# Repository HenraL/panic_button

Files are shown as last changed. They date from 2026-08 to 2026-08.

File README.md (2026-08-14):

<!-- 
-- +==== BEGIN AsperHeader =================+
-- LOGO:
--               @@@@@@@@@
--            @@@@       @@@@
--           @@  @@@@@@@@@  @@
--             @@@  @@@  @@@
--               @@@@@@@@@
--               @@ @@@ @@
--                 @@@@@
--                   @
--                  @@@
--                 @- #@
--                 @: @@
--                  @ @
--                  @ @
--                  @ @
--                 -@ @:
--                 =@ @*
--                 ## -#
--               %@@@@%@@@
--               @       @@
--            -@%@@@@#%@@@@@+
--         @@%+             =%@%#
--      =@@.                    @@#
--     %@:                       *@@-
--   *@*                           *%%
--  #@=         .   +*=             +@%
--  @*         :@@@@+-+@@@=          *@
-- %@          @@-        @@%         @@
-- %@         @%  %@@-@@@  #@         @@
-- @+        %@= @@     @@  @@        +@
-- @+        *@- @@     @@ -@%        +@
-- %@         @%  =@@@@@#  #@         @@
-- *@:         @@%       *@@+        :@%
--  @#           @%@*+@@%@#          #@
--  #@%                           . #@*
--    @%                           %@
--     @%@                       @@%
--      -@@%                   #@@=
--         *@@@             @@@#
--             @%@@@@@@@@@@@+
-- /STOP
-- PROJECT: AsperHeader
-- FILE: README.md
-- CREATION DATE: 14-08-2026
-- LAST Modified: 2:57:22 14-08-2026
-- DESCRIPTION:
-- A small panic beacon: reports its position to a server, falls back to SMS when unreachable, and advertises BLE (Find My-style) so phones can interact with it without an app.
-- /STOP
-- COPYRIGHT: (c) Asperguide
-- PURPOSE: This is the file in charge of introducing the repository.
-- // AR
-- +==== END AsperHeader =================+
-->
# Panic Button

A small **panic beacon** (target: no bigger than a finger; a palm if that size can't be
reached) that:

1. Updates its position towards a server.
2. If that is not available, sends an SMS (or similar).
3. Regardless of the above, advertises a BLE beacon (Apple Find My-style, Android hub,
   Samsung if they stray) so nearby phones can interact with it without any app.

Apple UWB is out of reach (proprietary Apple U1/U2 chip + MFi program) — phone interaction is
BLE only. Cost target: **< $50 / unit** (excluding the IoT/SIM plan).

## Repository layout

- `AGENTS.md` — rules and conventions for AI agents and contributors; read it first.
- `KiCad/v1/panic_button` — first board attempt (archive).
- `KiCad/v2/dev/panic_button_dev` — dev variant of the v2 circuit.
- `KiCad/v2/tiny/panic_button_tiny` — **active design** (KiCad 10): the tiny variant,
  as small as possible.
- `KiCad/v2/tiny/bom.md` — live bill of materials (strictly the BOM).
- `KiCad/v2/tiny/design.md` — design decisions, notes and open questions.
- `platformio/` — firmware (PlatformIO + Arduino on ESP32-C3). Comes **after** the circuit
  planning, not in parallel.
- `bonus/` — tools / environments / scratch (`bonus/tmp/`).

## Hardware status

- **Tiny** (active): ESP32-C3 (BLE) + SIM7670G LTE Cat1 (GNSS, SMS, HTTP/MQTT), Li-ion +
  USB-C charging, wake-on-motion accelerometer. Schematic in progress in KiCad 10.
- **Dev** = the tiny circuit + test infrastructure (test points, button array, richer LEDs,
  AirM2M Core ESP32-C3 module as the easier-to-mount MCU), functionally identical.

See `bom.md` for parts and prices, `design.md` for decisions.

## License

MIT — see `LICENSE`.

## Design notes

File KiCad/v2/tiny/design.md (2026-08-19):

<!-- 
-- +==== BEGIN AsperHeader =================+
-- LOGO:
--               @@@@@@@@@
--            @@@@       @@@@
--           @@  @@@@@@@@@  @@
--             @@@  @@@  @@@
--               @@@@@@@@@
--               @@ @@@ @@
--                 @@@@@
--                   @
--                  @@@
--                 @- #@
--                 @: @@
--                  @ @
--                  @ @
--                  @ @
--                 -@ @:
--                 =@ @*
--                 ## -#
--               %@@@@%@@@
--               @       @@
--            -@%@@@@#%@@@@@+
--         @@%+             =%@%#
--      =@@.                    @@#
--     %@:                       *@@-
--   *@*                           *%%
--  #@=         .   +*=             +@%
--  @*         :@@@@+-+@@@=          *@
-- %@          @@-        @@%         @@
-- %@         @%  %@@-@@@  #@         @@
-- @+        %@= @@     @@  @@        +@
-- @+        *@- @@     @@ -@%        +@
-- %@         @%  =@@@@@#  #@         @@
-- *@:         @@%       *@@+        :@%
--  @#           @%@*+@@%@#          #@
--  #@%                           . #@*
--    @%                           %@
--     @%@                       @@%
--      -@@%                   #@@=
--         *@@@             @@@#
--             @%@@@@@@@@@@@+
-- /STOP
-- PROJECT: AsperHeader
-- FILE: design.md
-- CREATION DATE: 14-08-2026
-- LAST Modified: 14:21:28 14-08-2026
-- DESCRIPTION:
-- A small panic beacon: reports its position to a server, falls back to SMS when unreachable, and advertises BLE (Find My-style) so phones can interact with it without an app.
-- /STOP
-- COPYRIGHT: (c) Asperguide
-- PURPOSE: This is the file containing the intended design of the circuit and why.
-- // AR
-- +==== END AsperHeader =================+
-->
# Design notes — panic_button_tiny (KiCad v2, "tiny" variant)

Working document for ideas, decisions, and open questions around the circuit. This is the
"sorting bin" — the strict bill of materials lives in `bom.md`.

## Goal

A **panic beacon** — small device (target: no bigger than a finger; a palm if that size can't
be reached). General-purpose; the current `tiny` variant happens to target a cat collar
(user's use case), but the design is not tied to that form factor.

Same family as the earlier v1/v2 dev designs, shrunk as far as practical.

## Tiny vs dev

- **Tiny** = the smallest possible circuit, as arranged in `panic_button_tiny/`.
- **Dev** = the tiny circuit + test infrastructure: test points, a testing array of buttons,
  richer debug status LEDs, and an **AirM2M Core ESP32-C3 module** as the easier-to-mount C3
  (same ESP32-C3FH4 die as the tiny's bare QFN, castellated module, onboard USB-C/buttons/RGB
  LED — Arduino framework supported). Functionally identical, same
  BOM family — any part dropped in tiny for footprint reasons is dropped in dev too. Dev
  extras only make the circuit easier to probe/debug; they never change what the circuit does.

## Hard functional spec (both variants)

1. Update the beacon's position towards a server.
2. If that is not available, send an SMS (or similar).
3. Regardless of the above, advertise BLE so phones can interact without an app
   (Apple Find My-style, Android hub, Samsung if they deviate).

Concretely the modem must provide: **a GNSS position fix, SMS, and HTTP/HTTPS + MQTT
(or similar) over LTE, all via AT commands**. Any modem substitution must keep all three.

## Decisions made

- **No UWB.** Apple UWB requires Apple's proprietary U1/U2 chip + MFi program — not reachable
  from an ESP32. Phone interaction relies on **BLE beacons only**:
  - Apple: Find My network accessory profile (BLE, keys-based, app-less).
  - Android: Find My Device hub (BLE).
  - Samsung: SmartThings Find (BLE, if they deviate from Android's hub).
- **Modem: SIM7670G** (24×24 mm) — the realistic floor for "Cat1 + GNSS + SMS + HTTP/MQTT in
  one part". Smaller Cat1 modules (EC200U, L610) are the same size class without GNSS; going
  smaller means LTE-M (loses SMS guarantees + needs a separate GNSS chip). Unless the
  footprint ceiling demands it, SIM7670G stays.
- **Position** comes from the SIM7670G's built-in GNSS (the `G` variant), with LTE cell
  triangulation as a fallback → POST to the server via HTTP(S) over LTE.
- **"If movement"** requires a MEMS accelerometer with a wake-on-motion interrupt to wake the
  MCU from deep sleep — neither the ESP32-C3 nor the modem can sense motion.
- **BMS is a DW01A-enable toggle (reworked 19-08-2026).** U6 (DW01A) + U7 (8205A) are
  **always populated**; the 8205A FETs are the only cell − → GND path. The toggle is a
  2-pad testpoint switch in the DW01A's GND pin (µA — nothing heats, no power-path switch):
  - Jumper **open** (default — cell with internal protection PCB, typical 603050 pouch):
    DW01A dead (no return path), OD/OC held high by **R12/R13 (470 kΩ) pull-ups to +BATT**
    → both gates on → the FETs conduct like a wire; the battery's own BMS owns the cell.
  - Jumper **bridged** (bare cell, no BMS): DW01A powered (VCC → BT1 (+) pre-switch, so
    protection stays armed while charging with the device off) → overcharge /
    overdischarge / overcurrent protection through the 8205A gates.
  - Silkscreen: "link only if the battery does not have a BMS; otherwise leave open".
- **Reverse-polarity protection: one high-side P-FET (Q1 = Si2305CDS, SOT-23).** The
  DW01A/8205A combo protects the cell, not a reversed plug — a reversed battery forward
  biases every body diode and kills the charger. Q1 (source = SW4 output, drain = +BATT,
  gate = GND) blocks that with zero drop. **Q2 (Si2301CDS) has no role — drop it.**
- **Reverse-powering protection (19-08-2026) — what protects what, and the rule:**
  - **Never series-diode the main rails** (+BATT, 3.3 V) — the 0.3–0.5 V Schottky drop is
    unacceptable in a battery device; that's exactly why Q1 is a FET (zero-drop ideal diode).
  - **Cell:** Q1 covers reversed cell insertion; DW01A/8205A block reverse cell current.
  - **5 V/VBUS (J2):** a series Schottky (SS14/SS24) blocks a reversed or mis-wired USB /
    bench supply — the TP4056 has no internal reverse-VBUS protection. [ADD, optional but
    cheap]. The optional USBLC6-2SC6 ESD sits on VBUS/CC for surges.
  - **J3 programming header:** the R10/R11 series resistors on U0TXD/U0RXD already block
    backfeed / reversed-plug damage to the C3 pins. Leave the J3 3V3 pin **unwired** (board
    is self-powered while flashing) or run it through a Schottky — never a straight
    connection to a live rail.
  - **Bench-lab safety net:** a TVS (e.g. 5 V on VBUS, 3.3 V on the 3V3 rail) clamps
    over/under-voltages; a reversed voltage forward-biases it → shorts → a series PPTC fuse
    opens. Only worth it if the device will be probed by hand a lot.
- **Battery-status LEDs on the charger** (LED1 red = charging, LED2 green = charged, off the
  TP4056 CHRG/STDBY open-drain outputs via R6/R7 1 kΩ) — wired, zero GPIOs, and the
  "charge status on the LED" spec is satisfied without touching the ESP. A GPIO-driven
  variant (drop Y2 → GPIO0/1) was considered and shelved as redundant.

## Firmware (PlatformIO)

- **One shared codebase** in `platformio/` — the same firmware for whatever PCB it ends up on.
- The `board = ...` declaration in `platformio.ini` acts mainly as a **RAM/flash + build-flag
  reference** (e.g. an ESP32-C3 board def) — it is not tied to our physical boards or their
  components.
- Less desirable alternative, still available: define **our own board entry** in the PIO
  config (custom memory/flags) instead of borrowing a stock one.

## Power / sleep notes

- SIM7670G supply range 3.4–4.3 V (typ. 4.0 V). A bare Li-ion (3.2–4.2 V) can sag under TX
  bursts — plan a steady 4 V rail (boost) or a fat bulk capacitor, plus a load switch so the
  modem draws nothing in deep sleep.
- Deep-sleep modem-off budget should let the beacon sit for weeks; wake only on motion
  interrupt, panic button, or periodic heart-beat timer.
- Each position report is a ~2 A burst for a few seconds — bulk caps on the modem rail matter
  as much as the cell.

## Component review (14-08-2026)

BOM checked against the target (< $50 excl. IoT plan) — still feasible at ~$20–46. Picks and
why:

- **Antenna for the C3**: the bare chip has no antenna in/on it (dev boards like the AirM2M
  Core / SuperMini carry their own PCB antenna). The tiny needs a **2.4 GHz SMD ceramic chip
  antenna (2450AT43A100-class) + LC matching network**, kept close to the RF pad / feed.
- **Modem stays SIM7670G**: cheaper Cat1 parts (e.g. A7670E / SIM7600-family variants) drop
  GNSS, which fails the hard spec (GNSS + SMS + HTTP/MQTT in one part).
- **Charger: TP4054** (SOT-23-5) instead of TP4056/IP5306 — smallest footprint, right current
  class; TP4056 only if we want the CHRG/STDBY LED pins; IP5306 rejected (5 V boost PMIC,
  wrong tool, bigger).
- **Accelerometer: LIS2DW12** (2×2 mm, ~7 µA). BMA400 as an alternative only if autonomous
  activity detection ever matters (10 µA, slightly pricier).
- **Modem rail**: low-quiescent boost in the ~1 A class (TPS61099-like) plus bulk caps covers
  the 2 A TX bursts; a higher-current part (TPS61023-like) is the headroom option. Both to be
  confirmed against the SIM7670G's burst profile + load switch for sleep.
- **USB-C charge-only**: 4/6-pin receptacle + 5.1 kΩ CC pull-downs; no D+/D- (tiny flashes
  via UART0 pads).

## Open questions

- Footprint ceiling for the cat: is a flat ~30×24 mm collar puck acceptable, or must the
  design fight for something smaller (which re-opens the modem question)?
- Report cadence when moving (sets cell size + charging expectations).
- One LED or none on the tiny version?
- Boot/reset as test pads instead of buttons on the tiny version (no switches on the cat)?
- Waterproofing strategy (sealed USB-C, charging contacts, enclosure) — shapes the final
  form factor.

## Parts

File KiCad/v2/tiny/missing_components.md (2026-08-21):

<!-- 
-- +==== BEGIN AsperHeader =================+
-- LOGO:
--               @@@@@@@@@
--            @@@@       @@@@
--           @@  @@@@@@@@@  @@
--             @@@  @@@  @@@
--               @@@@@@@@@
--               @@ @@@ @@
--                 @@@@@
--                   @
--                  @@@
--                 @- #@
--                 @: @@
--                  @ @
--                  @ @
--                  @ @
--                 -@ @:
--                 =@ @*
--                 ## -#
--               %@@@@%@@@
--               @       @@
--            -@%@@@@#%@@@@@+
--         @@%+             =%@%#
--      =@@.                    @@#
--     %@:                       *@@-
--   *@*                           *%%
--  #@=         .   +*=             +@%
--  @*         :@@@@+-+@@@=          *@
-- %@          @@-        @@%         @@
-- %@         @%  %@@-@@@  #@         @@
-- @+        %@= @@     @@  @@        +@
-- @+        *@- @@     @@ -@%        +@
-- %@         @%  =@@@@@#  #@         @@
-- *@:         @@%       *@@+        :@*
--  @#           @%@*+@@%@#          #@
--  #@%                           . #@*
--    @%                           %@
--     @%@                       @@%
--      -@@%                   #@@=
--         *@@@             @@@#
--             @%@@@@@@@@@@@+
-- /STOP
-- PROJECT: AsperHeader
-- FILE: missing_components.md
-- CREATION DATE: 16-08-2026
-- LAST Modified: 19:20:52 20-08-2026
-- DESCRIPTION:
-- A small panic beacon: reports its position to a server, falls back to SMS when unreachable, and advertises BLE (Find My-style) so phones can interact with it without an app.
-- /STOP
-- COPYRIGHT: (c) Asperguide
-- PURPOSE: This file lists every component the schematic still lacks, the symbol/footprint to use, and where each one links (pin numbers / nets).
-- // AR
-- +==== END AsperHeader =================+
-->
# Missing & present components — panic_button_tiny (as of 20-08-2026)

Complete wiring ledger, pin by pin. Verified against the saved schematic files
(embedded symbols, Y-flip applied). "PROPOSED" = sensible default, owner can
change; "OPEN" = decision pending.

> **Save state: 16:44 20-08-2026.** **Global annotation pass (all sheets share one
> numbering now) + FB divider WIRED ✓ + power-symbol swap (VBATT = #PWR054, -BATT = #PWR055)
> and REGRESSIONS FIXED (16:44: R3.2 re-routed to the FB node, C6 rewired VIN → GND).**
> Resistor map (old → new): R15→**R3** (47k
> RC0603FR-0747KL, modem_rail FB_LO), R14→**R4** (330k RC0603FR-07330KL, modem_rail
> FB_HI), R3→**R5** (10k_0402, brains GPIO9 pull-up), R4→**R6** (4.7k_0603, brains SDA
> pull-up), R5→**R7** (10k_0402, brains CHIP_EN pull-up), R6→**R8** (470k, li-ion OD
> pull-up), R7→**R9** (470k, li-ion OC pull-up), R8→**R10** (1k, li-ion CHRG LED),
> R9→**R11** (1k, li-ion STDBY LED), R10→**R12** (2.4k value, li-ion PROG),
> R11→**R13** (10k, li-ion stub), R12→**R14** (1k, uart U0TXD series), R13→**R15**
> (1k, uart U0RXD series). **FB divider DONE ✓: VOUT → R4 (330k) → FB → R3 (47k)
> → GND = 4.01 V (R3.2 re-routed to the FB row at 16:44, was on VOUT since 14:46).**
> **C6 FIXED ✓ (16:44): +BATT #PWR050 now feeds the VIN node directly; C6 = VIN → -BATT
> #PWR051 parallel decoupling** (was in series, blocking DC, since 13:14). UART swap FIXED ✓ (12:14). The `clock` and
> `uart` sheets connect to U5 via **hierarchical sheet pins on the sheet boxes inside
> brains** (not via labels on the brains canvas); clocks connected ✓, uart connected ✓
> (swap fixed). The pasted annotation log shows intermediate numbers; **the file is the
> truth** — this ledger quotes the saved state only.
>
> **Save state: 19:32 20-08-2026 (annotation pass, all sheets — clean ranges now:
> accelerometer #PWR042–043, radio_layout #PWR041, power_input #PWR044–048, modem_rail
> #PWR049–055, brains #PWR056–064, li-ion #PWR065–070, sound #PWR071, visual
> #PWR072–073, uart #PWR074–075, clock #PWR076–077).** modem_rail symbols also MOVED
> (nets re-verified ✓): +BATT #PWR050 (43.18,38.1), -BATT #PWR051 (46.99,20.32),
> GND #PWR052 (52.07,67.31), -BATT #PWR053 (57.15,64.77), VBATT #PWR054 (114.3,46.99),
> -BATT #PWR055 (127.0,57.15). **Design rule (user, 20-08-2026): the li-ion sheet uses
> WIRE connections only — no power symbols other than GND** (avoids an accidental
> feedback loop / spicy pillow). **DECIDED (19:5x): global labels on the CHARGING side
> only (the U8 block) — `+BATT` label @ U8 BAT junction, `5V` label @ U8 VCC, `3.3V`
> label @ U8 CE; the BATTERY side is pure wires (cell + chain BT1(+) → SW4 → Q1 → +BATT
> label point; cell − rail BT1(−) → U7, NO label/symbol). GND symbols stay. Consequence:
> modem_rail's `-BATT` symbols (#PWR051/#PWR053/#PWR055) lose their li-ion anchor — they
> are already on the GND node there (cell − = GND through U7) → rename them to `GND`
> (schematic change proposal, not applied yet).
>
> **21:5x: BMS → battery/charger RE-WIRED on the RESET li-ion1 (agent, verified — 0 mid-wire
> crossings this time):** U7 pin 2 (cell-side drain) → cell − rail (wires (44.45, 39.37) →
> (44.45, 44.45) → (60.96, 44.45)); U7 pin 5 (system-side drain) → new `GND #PWR071` @
> (93.98, 20.32) (wire (93.98, 26.67) → (93.98, 20.32)); U6 pin 5 VCC → `BT1 (+)` pre-SW4
> (wire (45.72, 30.48) → (54.61, 30.48) — TP1→TP3 gap bridge; the 20:2x route to (62.23,
> 30.48) crossed the TP4 rail and was reset by the owner). Net check ✓: BT1+/TP1/TP3/U6-VCC;
> BT1−/TP2/U6-GND/U7-2; U7-5/TP4/GND#PWR071. Symbols untouched (power symbols + PIN± kept).
> Backup: `bonus/tmp/li-ion_charging_handling1.kicad_sch.bak-reset-pre-wiring`.
> ⚠ KiCad was open during the edit — **reload li-ion1 in KiCad before saving** or the wires
> are clobbered. Still open: SW4/Q1 on-chain redo, toggle jumper pads [ADD], R8/R9.
>
> **20:06: WORKING COPY = `li-ion_charging_handling1.kicad_sch`** (duplicate of the
> li-ion sheet, both subsheets of power_input; KiCad re-annotated the duplicate — ref
> mapping in the li-ion section header). **Global-label conversion APPLIED on the
> duplicate:** `+BATT`/`3.3V`/`5V` power symbols → global labels (same anchor points,
> nets verified against wire endpoints), `-BATT` power symbol deleted (cell − = pure
> wires), redundant `PIN+(5V)`/`PIN-(5V)` labels deleted, GND symbols kept. Original
> sheet untouched. The DECIDED note above (U8/U7/BT1/…) describes the original's refs.

## How to read this file

- `A (pin N) -> B (pin M)` — the wire to draw (arrow = direction of the signal, not of the copper).
- `[ADD]` — component not on the sheets yet; `[PLACED]` — on the sheets but not wired.
- `✓` — already wired and verified by scan. Everything else still needs a wire.
- `REF (pin N)` uses the pin numbers printed on the placed symbol.
- Two-pin passives (R/C/L) have interchangeable pins 1/2.
- Power symbols (GND / 3.3V / 5V) connect across sheets **by name** — placing a
  `3.3V` symbol on another sheet ties it to the same net.

## Nets (power domains)

| Net | Meaning | Source (component-first) |
| --- | --- | --- |
| `5V` | USB-C input rail | J2 VBUS |
| `3.3V` | logic rail | U3 V_OUT (ME6211) |
| `BT1 (+)` | battery positive | U11 pin 5 BAT (TP4056), U4 pin 7 VIN, U9 pin 5 VCC (DW01A) — cell +, a *net name* not a connector |
| `BT1 (−)` | battery negative (raw) | U10 pin 2 (cell-side drain), Q2 gate, toggle jumper pad 2 — the cell − rail; **pure wires on li-ion1, no symbol/label** (20:06) |
| `U1 VBAT pins 55–57` (net `U1 VBAT pins 55–57`) | ~4.0 V modem rail | U4 V_OUT (TPS61022) |
| `GND` | ground | everywhere |

## Present on the sheets

| Sheet | Ref | Part | Wiring |
| ----- | --- | ---- | --- |
| brains | U5 | ESP32-C3 (QFN-32) | done ✓ (63 wires) |
| clock | Y1 | **32.768 kHz crystal (CTS3-32.768-12.5-20-R)** — re-ref'd 01:06 (was Y2) | done ✓ (25 wires) |
| clock | Y2 | **C3E-40.000-12-1010-X (40 MHz)** — re-ref'd 01:06 (was Y1) | done ✓ |
| clock | C13, C16 | 22 pF load caps (Y1 32K: XTAL_32K_N + XTAL_32K_P) | done ✓ |
| clock | C14, C15 | 22 pF load caps (Y2 40 MHz: XTAL_P + XTAL_N) | done ✓ |
| brains | C8–C11 | 100 nF decoupling caps (renumbered 00:28, were C10–C13) | done ✓ (pin 1 → GND, pin 2 → 3.3V) |
| brains | R5 | 10 kΩ GPIO9 pull-up (= R_BOOT, 10k_0402) | done ✓ (GPIO9 → 3.3V #PWR056) |
| brains | SW1 | tact switch — BOOT (GPIO9) | done ✓ (pin 2 → GPIO9, pin 1 → GND #PWR057, pin-touch) |
| brains | SW2 | tact switch — RST (CHIP_EN) | done ✓ (pin 1 → CHIP_EN junction, pin 2 → GND #PWR062) |
| brains | SW3 | tact switch — status button (**MTMS = GPIO5**) | done ✓ (pin 1 → U5 pin 9 MTMS tip (132.08, 57.15), pin 2 → GND #PWR064) |
| brains | R6 | 4.7 kΩ SDA pull-up | **done ✓** — `3.3V #PWR058 @ (71.12, 50.8)` → R6 pin 2 → pin 1 → `I2C (SDA)` label + GPIO8 |
| brains | R7 | 10 kΩ CHIP_EN pull-up (= R_EN, 10k_0402) | done ✓ (3.3V #PWR063 @ (180.34, 52.07) → pin 2, pin 1 → CHIP_EN junction) |
| uart | J3 | 1×6 UART programming header | done ✓ — all 6 pins wired (3V3, GND, U0TXD, U0RXD, CHIP_EN, GPIO9) |
| uart | R14, R15 | 1 kΩ series (R_UART pair, U0TXD/U0RXD) | done ✓ |
| uart | TP8–TP13 | test points (3V3, U0TXD, CHIP_EN, GND, U0RXD, GPIO9) | done ✓ — each wired to its J3 row |
| visual | D1 | WS2812B-2020 status LED | done ✓ (8 wires, D1 @ (43.18, 27.94), C12 100 nF across VDD/VSS, `+BATT #PWR072` on VDD, `LED_DIN` wired) |
| power_input | J2 | USB-C charge-only | done ✓ (32 wires) |
| power_input | U3 | ME6211C33M5 (3.3 V LDO) | done ✓ |
| power_input | R1, R2 | 5.1 kΩ CC pull-downs | done ✓ (CC2→R2→GND wired; CC1→R1→GND pin-coincident, see note) |
| li-ion_charging_handling1 (WORKING COPY — RESET 21:5x, refs = ORIGINAL's: U6/U7/U8/BT1/SW4/Q1) | U6 | DW01A protection | wired ✓ — VCC → BT1 (+) powered ✓ (21:5x), GND → U7 pin 2 on cell − rail ✓ (toggle-split pending) |
| li-ion_charging_handling1 (WORKING COPY — RESET 21:5x, refs = ORIGINAL's: U6/U7/U8/BT1/SW4/Q1) | U7 | 8205A protection FETs | wired ✓ — pin 2 on cell − rail ✓, pin 5 on GND ✓ (21:5x) |
| li-ion_charging_handling1 (WORKING COPY) | U11 | TP4056-42-ESOP8 charger | wired ✓ |
| li-ion_charging_handling1 (WORKING COPY) | BT2 | `Device:Battery_Cell` (1000 mAh) | wired ✓ (→ TP14/TP15 only; ⚠ on-chain open) |
| li-ion_charging_handling1 (WORKING COPY) | R16, R17 | 470 kΩ OD/OC pull-ups (BMS toggle) | ⚠ placed (13:14) but 0 wires — see section |
| li-ion_charging_handling1 (WORKING COPY) | R18, R19 | 1 kΩ LED resistors (CHRG/STDBY) | wired ✓ |
| li-ion_charging_handling1 (WORKING COPY) | R20 | 1.2 kΩ PROG (Value = 2.4 kΩ → 500 mA) | wired ✓ |
| li-ion_charging_handling1 (WORKING COPY) | R21 | 10 kΩ stub (TP19/TP20) | ⚠ floating stub — see section |
| modem_rail | U4 | TPS61022 boost (modem rail) | **DONE ✓ (01:06 rebuild + 13:14 divider + 16:44 fixes)** — VIN/L2/SW/EN/MODE/GND/output cap ✓; FB divider R4 (330k) + R3 (47k) = 4.01 V ✓ (16:44: R3.2 re-routed to FB); C6 rewired VIN → -BATT ✓ (16:44) — only VBATT → U1 VBAT pins 55–57 remains |
| network_and_gps | U1 | SIM7670G-LNGV modem | to wire (GND stubs all terminated ✓, 39 wires) |
| network_and_gps | J1 | JAE SF72S006 SIM holder | to wire (GND symbol placed ✓) |
| accelerometer | U2 | LIS2DE12 (design says LIS2DW12 — OPEN) | to wire (0 wires; Vdd = 3.3V touch ✓, GND touch ✓) |
| sound | LS1 | `PCM_SparkFun-Electromechanical:PKLCS1212E4001-R1` (passive piezo) | **DONE ✓ (00:28)** — `LS1.P -> Buzzer+` label, `LS1.N -> GND #PWR071` direct |
| radio_layout | E1 | 2450AT18A0100001E chip antenna | to wire |
| radio_layout | L1, C1 | 4.7 nH + 1.2 pF BLE match | to wire |

## Status ledger (schematic state = 13:14 save, 20-08-2026)

One-glance DONE / NOT-DONE per sheet. The U5 pin-by-pin table below is the authoritative
state of the ESP32-C3. Subsheet connections (`clock`, `uart`) go through **sheet pins on
the sheet boxes inside brains** — pin = port on the box, wired to U5 on the brains
canvas; the matching `hierarchical_label` inside the subsheet is the other end.

### brains — U5 (ESP32-C3) pin-by-pin

| U5 pin | Name | State |
| --- | ---- | ----- |
| 2/3 | VDD3P3 | **DONE ✓** 3.3V bus (pin 3 = hidden alias of pin 2, same tip) |
| 11/17/18/31/32 | VDD3P3_RTC/CPU/SPI/VDDA | **DONE ✓** 3.3V bus (pin 31 = hidden alias of pin 32, same tip) |
| 33 | GND | **DONE ✓** (pin-touch) |
| 29/30 | XTAL_N/P (40 MHz) | **DONE ✓ (01:06)** — clock sheet pin `XTAL_N`/`XTAL_P` @ (76.2, 80.01/82.55) → direct wires to pins 29/30 (tips (86.36, 80.01/82.55)) ✓ |
| 4/5 | XTAL_32K_N/P (32.768 kHz) | **DONE ✓ (01:06)** — clock sheet pins `XTAL_32K_N`/`XTAL_32K_P` @ (76.2, 77.47/74.93) → direct wires to pins 5/4 (tips (86.36, 77.47/74.93)) ✓ |
| 7 | CHIP_EN | **DONE ✓** R7 pull-up + SW2 + **`UART_CHIP_EN` sheet pin connected** (junction @ (153.67, 52.07): U5 pin 7 tip (132.08, 52.07) → (153.67, 52.07) → (153.67, 101.6) = UART sheet pin) |
| 9 | MTMS (= GPIO5) | **DONE ✓** SW3 status button (pin-touch) |
| 10 | MTDI (= GPIO4) | **DONE ✓** Motion_wake label → accelerometer (matches) |
| 15 | GPIO9 | **DONE ✓** R5 pull-up + SW1 — `I2C (SCL)` ✓ — **⚠ UART_GPIO9 sheet pin wired here (swap FIXED 12:14)** |
| 14 | GPIO8 | **DONE ✓** R6 pull-up + `I2C (SDA)` ✓ |
| 6 | GPIO2 | **DONE ✓** battery_voltage_sense label → modem sheet (matches) |
| 8 | GPIO3 | **DONE ✓** power-on_pulse label → modem sheet (matches) — **buzzer conflict RESOLVED (19-08): buzzer on GPIO7** |
| 13 | MTDO (= GPIO7) | **DONE ✓ (00:28)** — `Buzzer+` label ADDED on brains → sound sheet LS1 ✓ (see sound section) |
| 12 | MTCK (= GPIO6) | spare — kept free for hardware JTAG (MTCK = the clock line) |
| 27/28 | U0RXD/U0TXD | **DONE ✓** `UART (RXD)`/`UART (TXD)` labels → modem sheet (matches). J3 side connected via sheet pins ✓ — **swap FIXED (12:14, re-verified 16:5x): `UART_U0RXD` → U5 pin 27, `UART_GPIO9` → U5 pin 15, `UART_U0TXD` → pin 28** (see uart section) |
| 16 | GPIO10 | **DONE ✓** `LED_DIN` label → visual sheet (matches) |
| 25 | GPIO18 | **DONE ✓** modem_status label anchored on the pin tip (⚠ STATUS is 1.8 V logic, needs level-shift) |
| 26 | GPIO19 | **DONE ✓** modem_rail_switch label anchored on the pin tip |
| 1 | LNA_IN | untouched (antenna lives on radio_layout) |

### All sheets, done vs not

| Sheet | Done | Not done |
| ----- | ---- | --- |
| brains | everything above + R5/R6/R7 + SW1/SW2/SW3 (63 wires, 13:14) | ✓ **complete — UART sheet-pin swap FIXED (12:14)** |
| clock | **DONE ✓ (01:06)** — Y1 32K CTS3 + Y2 40 MHz C3E + C13–C16 (22 pF), 25 wires, **connected to U5 via sheet pins** (pins 4/5/29/30) | nothing |
| uart | J3 + R14/R15 + TP8–TP13 + 4 labels (14 wires), **connected to U5 via sheet pins** | ✓ **complete — swap FIXED (12:14)** |
| power_input | **complete ✓** (32 wires, verified twice) | cosmetic: draw CC1→R1 and R2 pin 2→GND wires |
| visual | D1 WS2812B wired ✓ (8 wires) + C12 decap ✓ + `+BATT #PWR072` ✓ | — |
| network_and_gps | 39 GND stubs + GND symbol + 5 labels (UART TXD/RXD, battery_voltage_sense, power-on_pulse, modem_status) | all signal wiring U1/J1; STATUS level-shift |
| accelerometer | U2 placed, Vdd/GND touches, 3 labels (I2C (SCL)/(SDA), Motion_wake) | all wiring (0 wires) |
| modem_rail | **DONE ✓ (01:06 rebuild + 13:14 divider + 16:44 fixes)** — VIN ✓ (+BATT → L2 → SW), EN ✓ (modem_rail_switch), MODE ✓ (+BATT), GND ✓, output cap C7 ✓, FB divider R4 (330k) + R3 (47k) = 4.01 V ✓, C6 = VIN → -BATT decoupling ✓ | `#PWR054 VBATT -> U1 VBAT pins 55–57` (network_and_gps sheet) — the ~2 A TX burst lives there |
| li-ion_charging_handling1 (WORKING COPY — RESET 21:5x, refs = ORIGINAL's) | U6/U7/U8/BT1/SW4/Q1 wired (65 wires), power symbols + PIN± labels kept (21:5x) | **BMS → battery/charger wired ✓ (21:5x, agent): U7 pin 2 → cell − rail, U7 pin 5 → GND #PWR071, U6 VCC → BT1 (+)** — remaining: cell-side net (BT1 ↔ SW4/Q1/+BATT — Q1/SW4 0 wires), toggle jumper + R8/R9 (470k, placed unwired) |
| sound | **DONE ✓ (00:28)** — LS1.P → `Buzzer+` label, LS1.N → GND direct (6 wires) | — |
| radio_layout | E1/L1/C1 placed | **everything** (0 wires) |

### Open decisions (blocking wiring)

1. **GPIO3: buzzer (BZ1) vs power-on pulse (PWRKEY)** — **RESOLVED (19-08): buzzer → GPIO7 (MTDO), GPIO3 keeps PWRKEY** — wired both sides ✓ (00:28)
2. **D1 (WS2812) VDD rail** — **RESOLVED (00:30): `+BATT`** (sourced on li-ion1 U11 pin 5 BAT; visual has `+BATT #PWR072`)
3. **Charge-status on LED** — **RESOLVED (19-08): option B in effect** (LED1/LED2 CHRG/STDBY pair wired on li-ion; no ESP-input variant)
4. **U2: LIS2DE12 placed vs design LIS2DW12** — OPEN

## ASCII wiring references (for the wrong / unclear connections)

### 1. R6 — I2C SDA pull-up (brains sheet, DONE ✓, latest save)

```txt
NOW:  full pull-up chain verified — 3.3V symbol (#PWR058) @ (71.12, 50.8), R6 @ (77.47, 50.8)
      rot 90 (horizontal), pin 2 @ (73.66, 50.8) ← wire ← 3.3V; pin 1 @ (81.28, 50.8)
      → wire down → row y = 52.07 → I2C (SDA) label @ (71.12, 52.07) → GPIO8 @ (86.36, 52.07)

    #PWR058 3.3V ── R6 pin 2 ──[R6]── R6 pin 1 ──┬── I2C (SDA) label ──→ U2 pin 4
                                                 └── GPIO8 (U5 pin 14)
```

### 2. I2C (SCL) label — FIXED ✓ (brains sheet, latest save)

```txt
NOW (fixed):  the label moved to the GPIO9 side of R5 — label @ (44.45, 57.15),
              vertical stub (48.26, 57.15)→(48.26, 54.61), then the GPIO9 row
              (44.45→86.36, 54.61) → GPIO9 (U5 pin 15). R5: 3.3V #PWR056 @ (34.29, 54.61)
              → pin 1 @ (36.83, 54.61), pin 2 @ (44.45, 54.61) = row start.

    3.3V ── R5 10k ──┬── GPIO9
                     └── I2C (SCL) label ──→ U2 pin 1   (label on the MCU node) ✓
```

### 3. Cross-sheet net names — ALL FIXED ✓ (all sheets, latest save)

```txt
KiCad labels are case- AND punctuation-sensitive. Pick ONE name, use it on both sheets:

    brains                         other sheet          verdict
    ─────────────────────────────  ──────────────────   ────────────────
    "UART (TXD)"                   "UART (TXD)"         ✓ MATCH (modem sheet renamed)
    "UART (RXD)"                   "UART (RXD)"         ✓ MATCH
    "battery_voltage_sense"        "battery_voltage_sense"  ✓ FIXED (22:30)
    "power-on_pulse"               "power-on_pulse"     ✓ MATCH (modem sheet renamed to hyphen)
    "Motion_wake"                  "Motion_wake"        ✓ OK
    "modem_status"                 "modem_status"       ✓ OK — and now anchored ON GPIO18's tip
    "modem_rail_switch"            "modem_rail_switch"  ✓ OK — and now anchored ON GPIO19's tip
```

### 4. LED data line — DONE ✓ (23:52 save, brains ↔ visual sheets)

```txt
[visual ✓]  "LED_DIN" label @ (34.29, 27.94) — wire — D1 pin 3 (DIN) @ (35.56, 27.94)
[brains ✓]  "LED_DIN" label @ (78.74, 57.15) — wire — U5 pin 16 (GPIO10) @ (86.36, 57.15)

    brains:  U5 pin 16 GPIO10 ── "LED_DIN" ──⇄── "LED_DIN" ── D1 DIN   (visual) ✓ CLOSED
```

### 5. D1 VDD — power rail (visual sheet; WS2812B needs 3.7–5.3 V)

> **✅ DONE ✓ (verified 16:5x):** D1 VDD is on the `+BATT` rail and the rail IS sourced on
> li-ion1 — `visual: +BATT #PWR072 → C12 (100 nF) → D1.4 (VDD)`; `li-ion1: +BATT global
> label → U11 pin 5 (BAT)`. **No schematic update needed.** (The old "U6 pin 5 BAT" note
> below predates the 00:28 annotation — the charger is U11, and its BAT pin already sources +BATT.)

```txt
USER DECISION (23:52 save): D1 VDD is on the "+BATT" power symbol (now #PWR072 after the 01:56 annotation) —
the rail must be SOURCED on the li-ion sheet: place a "+BATT" power symbol at
U6 pin 5 BAT (downstream of SLIDE_SW). See visual section for the honest notes
(U6 BAT = same node as the cell +; Q2 P-FET turns +BATT into the protected rail;
3.3V from U3 = the regulated alternative, dimmer).

    li-ion:  BT1 (+) ── Q2 [optional] ── U6 pin 5 BAT ── [+BATT symbol]
    visual:  [+BATT symbol] ── C14 100nF ── D1 VDD
```

### 6. modem_rail sheet — the two wrong nets (biggest electrical risk)

> **✅ FIXED ✓ (01:06 rebuild + 16:44 regressions):** VIN now on the `+BATT` rail (was
> 3.3 V), output net is `VBATT` (was 5 V), C6 = VIN → -BATT decoupling, FB divider R4
> (330k) + R3 (47k) = 4.01 V. **modem_rail itself is done — no update needed.** The only
> wire left for this rail is `VBATT → U1 VBAT pins 55–57`, to be drawn on the
> network_and_gps sheet. (The ASCII below is the historical pre-rebuild state.)

```txt
NOW (wrong):  U4 VIN on the 3.3V net;  U4 VOUT labeled 5V

    [3.3V] ── U4 VIN      (500 mA LDO can't feed 2 A TX bursts)
    U4 VOUT ── [5V]       (SIM7670G VBAT max = 4.3 V → would kill the modem)

FIX:

    BT1 (+) pin ──┬────────────── U4 pin 7 VIN        (battery rail, +22µF)
               └── L2 1µH ──── U4 pin 2 SW
    U4 pin 3 VOUT ──┬── U1 VBAT (4.0 V) (4.0 V net) ──→ U1 VBAT pins 55–57   (+22µF)
                    └── R_FB_HI 700k ──┬── U4 pin 4 FB
                                       └── R_FB_LO 100k ── GND
    U4 pin 5 EN ──── (from brains: "modem_rail_switch" label ⇄ GPIO19)
    U4 pin 6 MODE ── BT1 (+) pin      (PFM, light-load idle)
    U4 pin 1 GND ─── GND
```

### 7. R_UART_A/B — programmer backfeed protection — DONE ✓ (uart sheet)

```txt
The two 1 kΩ (R14/R15) sit IN SERIES on U0TXD (J3 pin 3) and U0RXD (J3 pin 4), on the
uart sheet, between the labels and J3 — everything downstream (J3, TPs, labels) is on
the protected side. 5 V TX → clamp current ~1.5 mA; TX↔TX conflict → ~3.3 mA max;
zero signal impact at 115200 baud. 3V3/GND/CHIP_EN/GPIO9 rows are direct wires (correct).

    uart sheet, y = 24.13:  UART_U0TXD label ── R14 1k ──┬── J3 pin 3 ─ TP9
    uart sheet, y = 26.67:  UART_U0RXD label ── R15 1k ──┬── J3 pin 4 ─ TP12
```

## Wiring — already done (verified by scan, 01:06 20-08-2026)

**brains (63 wires — re-laid out 19-08; U5 @ (109.22, 67.31)):**

- **3.3 V rail — all power pins:** `3.3V #PWR059 @ (99.06, 17.78) -> C8/C9/C10/C11 (pin 2)`
  and `-> U5 (pins 3 VDD3P3, 11 VDD3P3_RTC, 17 VDD3P3_CPU, 18 VDD_SPI, 32 VDDA)` ✓
  (pin 3 = hidden alias of pin 2, pin 31 = hidden alias of pin 32 — same tips, connected)
- **Decoupling:** `C8/C9/C10/C11 (pin 1) -> GND #PWR061` ✓
- `U5 (pin 33 GND) -> GND #PWR060` ✓ (pin-touch)
- **R_EN (R7) @ (172.72, 52.07):** `3.3V #PWR063 @ (180.34, 52.07) -> R7 (pin 2)` ✓ —
  `R7 (pin 1) -> U5 (pin 7 CHIP_EN)` ✓ (real wire, via the CHIP_EN junction @ (153.67, 52.07))
- **R_BOOT (R5) @ (40.64, 54.61):** `3.3V #PWR056 @ (34.29, 54.61) -> R5 (pin 1)` ✓ —
  `R5 (pin 2) -> U5 (pin 15 GPIO9)` ✓ — `I2C (SCL)` label on the GPIO9 node ✓
- **R_SDA (R6) @ (77.47, 50.8) rot 90:** `3.3V #PWR058 @ (71.12, 50.8) -> R6 (pin 2)`
  ✓ — `R6 (pin 1) -> I2C (SDA)` label + GPIO8 ✓
- **SW_RST (SW2) @ (158.75, 46.99):** `SW2 (pin 1) -> CHIP_EN` ✓, `SW2 (pin 2) -> GND
  #PWR062` ✓ (pin-touch)
- **SW_BOOT (SW1) @ (54.61, 52.07):** `SW1 (pin 2) -> GPIO9` ✓, `SW1 (pin 1) -> GND
  #PWR057` ✓ (pin-touch)
- **Status button (SW3) @ (191.77, 57.15):** `SW3 (pin 1) -> U5 (pin 9 MTMS)` ✓ (pin-touch
  @ (132.08, 57.15)), `SW3 (pin 2) -> GND #PWR064` ✓ (pin-touch)
- **Labels (11):** `power-on_pulse` (GPIO3), `battery_voltage_sense` (GPIO2),
  `Motion_wake` (pin 10 MTDI), `I2C (SCL)` (GPIO9), `I2C (SDA)` (GPIO8), `LED_DIN`
  (GPIO10), `modem_status` (GPIO18), `modem_rail_switch` (GPIO19), `UART (TXD)`/
  `UART (RXD)` (pins 28/27), **`Buzzer+` (pin 13 MTDO, ADDED 00:28 ✓)** — all match
  their counterpart sheets
- **Subsheet sheet pins (01:06):** clock box @ (60.96, 72.39) — 4 pins `XTAL_32K_P/N`
  @ (76.2, 74.93/77.47) + `XTAL_N/P` @ (76.2, 80.01/82.55), each wired to its U5 pin
  (4/5/29/30, tips (86.36, 74.93/77.47/80.01/82.55)) ✓ **clocks CONNECTED**; uart box @
  (137.16, 101.6) — 4 pins, **U0TXD + CHIP_EN correct, U0RXD↔GPIO9 SWAPPED** (see uart
  section)

**clock (NEW sheet, 00:28 — 25 wires, re-ref'd 01:06):**

- **Y1 (32.768 kHz, CTS3-32.768-12.5-20-R) @ (39.37, 29.21):** `Y1 (pin 1) -> C13 ->
  XTAL_32K_N` label, `Y1 (pin 2) -> C16 -> XTAL_32K_P` label ✓
- **Y2 (40 MHz, C3E40000121010X) @ (38.1, 53.34):** `Y2 (pin 1) -> C14 -> XTAL_P` label,
  `Y2 (pin 3) -> C15 -> XTAL_N` label, `Y2 (pin 4 case GND) -> GND #PWR077` ✓
- `C13/C16 (far ends) -> GND #PWR077`, `C14/C15 (far ends) -> GND #PWR077` ✓
- 4 hierarchical labels + 4 sheet pins on the brains box — **CONNECTED to U5 pins 4/5/29/30 ✓**

**power_input (32 wires, 19:37 save):**

- `J2 (VBUS pin 1) -> 5V` and `J2 (VBUS pin 2) -> 5V` ✓
- `5V -> U3 (pin 1 V_IN)` ✓
- `U3 (pin 5 V_OUT) -> 3.3V` ✓
- `J2 (GND pin 1) -> GND`, `J2 (GND pin 2) -> GND`, `J2 (SHIELD) -> GND` ✓
- `U3 (pin 2 V_SS) -> GND` ✓
- `J2 (CC1) -> R1 (pin 1)` ✓ (pins touch, no wire needed) — `R1 (pin 2) -> GND` ✓
- `J2 (CC2) -> R2 (pin 1)` ✓ — `R2 (pin 2) -> GND` ✓

## Wiring — TO DO, sheet by sheet

### brains

| Wire | Notes |
| ----- | ---- |
| `U5 (pin 27 U0RXD) -> U1 (pin 9 TXD)` | modem AT UART — label "UART (RXD)" ✓ matches modem sheet |
| `U5 (pin 28 U0TXD) -> U1 (pin 10 RXD)` | modem AT UART — label "UART (TXD)" ✓ matches modem sheet |
| `U5 (pin 14 GPIO8) -> U2 (pin 4 SDA/SDI)` | I2C SDA — **DONE ✓ (pull-up R4 to 3.3V)**; label "I2C (SDA)" ✓ |
| `U5 (pin 15 GPIO9) -> U2 (pin 1 SCL/SPC)` | I2C SCL — **DONE ✓ (R3 pull-up doubles as SCL pull-up)** |
| `U5 (pin 10 MTDI = GPIO4) -> U2 (pin 12 INT1)` | motion wake — label "Motion_wake" ✓ matches accelerometer |
| `U5 (pin 6 GPIO2) -> U1 (pin 51 VBAT_ADC)` | battery voltage sense — label ✓ matches |
| `U5 (pin 9 MTMS = GPIO5) -> SW3 (pin 1)` | **DONE ✓** status button; `SW3 (pin 2) -> GND` — short = battery color on D1, long = BLE pairing (LED, not buzzer) |
| `U5 (pin 8 GPIO3) -> U1 (pin 1 PWRKEY)` | power-on pulse — label ✓ matches — **buzzer conflict RESOLVED (19-08): buzzer on GPIO7** |
| `U5 (pin 25 GPIO18) -> U1 (pin 66 STATUS)` | modem status — label anchored on the pin tip ✓; ⚠ STATUS is 1.8 V logic, needs level-shift |
| `U5 (pin 26 GPIO19) -> U4 (pin 5 EN)` | modem rail switch — label anchored on the pin tip ✓ |
| `U5 (pin 16 GPIO10) -> D1 (pin 3 DIN)` | status LED data — **DONE ✓** — `LED_DIN` on both sheets, both wired |
| `U5 (pin 13 MTDO = GPIO7) -> LS1 (pin 1 +)` | **DONE ✓ (00:28)** — `Buzzer+` label added on brains, matches sound ✓ |
| `U5 (pins 29/30 XTAL_P/N) -> clock sheet` | **DONE ✓ (01:06)** — sheet pin `XTAL_P` @ (76.2, 82.55) → U5 pin 30, `XTAL_N` @ (76.2, 80.01) → U5 pin 29 |
| `U5 (pins 4/5 XTAL_32K_P/N) -> clock sheet` | **DONE ✓ (01:06)** — sheet pin `XTAL_32K_P` @ (76.2, 74.93) → U5 pin 4, `XTAL_32K_N` @ (76.2, 77.47) → U5 pin 5 |
| `U5 (pin 28 U0TXD) -> J3 (pin 3)` + `U5 (pin 27 U0RXD) -> J3 (pin 4)` | **DONE ✓ (12:14 swap fix, re-verified 16:5x)** — `UART_U0TXD` @ (137.16, 111.76) → U5 pin 28 ✓; `UART_U0RXD` @ (137.16, 109.22) → U5 pin 27 ✓ (drop x=82.55, y 69.85→109.22); `UART_GPIO9` @ (137.16, 114.3) → U5 pin 15 ✓ (drop x=80.01, y 54.61→114.3) |
| `U5 (pin 7 CHIP_EN) -> J3 (pin 5)` | **DONE ✓ (01:06)** — `UART_CHIP_EN` @ (153.67, 101.6), vertical drop to junction @ (153.67, 52.07) ← U5 pin 7 + SW2.1 + R5.1 |
| `U5 (pin 15 GPIO9) -> J3 (pin 6)` | **DONE ✓ (12:14 swap fix, re-verified 16:5x)** — brains: GPIO9 row (y=54.61) → drop x=80.01 → `UART_GPIO9` sheet pin @ (137.16, 114.3); uart: label @ (31.75, 31.75) → TP13 → J3 pin 6 ✓ |
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

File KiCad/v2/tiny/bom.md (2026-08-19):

<!-- 
-- +==== BEGIN AsperHeader =================+
-- LOGO:
--               @@@@@@@@@
--            @@@@       @@@@
--           @@  @@@@@@@@@  @@
--             @@@  @@@  @@@
--               @@@@@@@@@
--               @@ @@@ @@
--                 @@@@@
--                   @
--                  @@@
--                 @- #@
--                 @: @@
--                  @ @
--                  @ @
--                  @ @
--                 -@ @:
--                 =@ @*
--                 ## -#
--               %@@@@%@@@
--               @       @@
--            -@%@@@@#%@@@@@+
--         @@%+             =%@%#
--      =@@.                    @@#
--     %@:                       *@@-
--   *@*                           *%%
--  #@=         .   +*=             +@%
--  @*         :@@@@+-+@@@=          *@
-- %@          @@-        @@%         @@
-- %@         @%  %@@-@@@  #@         @@
-- @+        %@= @@     @@  @@        +@
-- @+        *@- @@     @@ -@%        +@
-- %@         @%  =@@@@@#  #@         @@
-- *@:         @@%       *@@+        :@%
--  @#           @%@*+@@%@#          #@
--  #@%                           . #@*
--    @%                           %@
--     @%@                       @@%
--      -@@%                   #@@=
--         *@@@             @@@#
--             @%@@@@@@@@@@@+
-- /STOP
-- PROJECT: AsperHeader
-- FILE: bom.md
-- CREATION DATE: 14-08-2026
-- LAST Modified: 2:58:21 14-08-2026
-- DESCRIPTION:
-- A small panic beacon: reports its position to a server, falls back to SMS when unreachable, and advertises BLE (Find My-style) so phones can interact with it without an app.
-- /STOP
-- COPYRIGHT: (c) Asperguide
-- PURPOSE: This is the file containing the list of the components used in the schematic.
-- // AR
-- +==== END AsperHeader =================+
-->
# BOM — panic_button_tiny (KiCad v2, "tiny" variant)

Live bill of materials as of 14-08-2026 (KiCad 10). Prices are rough single-unit estimates
(LCSC / Aliexpress / JLCPCB, USD) — verify before ordering. Cost target: **< $50 / unit,
excluding the IoT/SIM plan** (see `design.md` for all decisions and notes).

## Estimated BOM

| Qty | Ref | Part | Est. price | Notes |
| ----- | ----- | --- | ---: | --- |
| 1 | U5 | ESP32-C3FH4 (QFN-32 5x5, 4MB flash) | $1.50–2.50 | MCU + BLE 5.0 advertising; boot = GPIO9, reset = EN — placed on brains |
| 1 | – | 2.4 GHz ceramic chip antenna (2450AT43A100-class) + LC match | $0.30–0.80 | C3 has no antenna in/on the chip — it needs its own |
| 1 | U1 | SIM7670G LTE Cat1 module | $10–20 | 4G, GNSS, SMS + HTTP/HTTPS + MQTT via AT; IoT M2M SIM — placed on network_and_gps |
| 1 | U8 | TP4056-42-ESOP8 (charger) | $0.15–0.40 | placed as U8 on the Li-ion subsheet; CHRG/STDBY open-drain outputs drive the status LEDs (LED1/LED2) |
| 1 | U6 | DW01A (protection IC) | $0.05–0.15 | **always populated** — enabled/disabled by the toggle jumper on its GND pin (open = battery has its own BMS, closed = bare cell) |
| 1 | U7 | 8205A dual N-MOSFET (SOT-23-6) | $0.07–0.15 | **always populated** — the only cell − → GND path; gates held on by R12/R13 pull-ups when the DW01A is unpowered |
| 1 | Q1 | Si2305CDS P-MOSFET (SOT-23) | $0.05–0.10 | reverse-polarity protection, zero drop — placed, to wire (SW4 → Q1 → +BATT) |
| – | Q2 | Si2301CDS P-MOSFET (SOT-23) | – | **no role — remove** (Q1 covers reverse protection) |
| 1 | SW4 | SPDT slide switch (SMD 6.7×2.6 mm) | $0.20–0.40 | hard on/off in the BT1 (+) path — placed |
| 1 | BT1 | Li-ion pouch cell, 3.7 V (603050-class, 1000 mAh) | $2–5 | size driven by 4G TX bursts + sleep budget |
| 2 | LED1/LED2 | 1.8 mm SMD LED (red + green) | $0.10–0.30 | charging / charged from TP4056 CHRG/STDBY — wired |
| 1 | R8 | 1.2 kΩ 0603 (PROG) | – | TP4056 charge current: 1.2 kΩ = 1 A; 2.4 kΩ = 500 mA if preferred |
| 2 | R6/R7 | 1 kΩ 0603 | – | LED1/LED2 series resistors — wired |
| 2 | TP_sw | 2× TestPoint_1.25mm pads facing each other | $0.02 | U6 GND ↔ cell − — the DW01A-enable toggle (µA); ships OPEN (with-BMS default), solder bridge = closed |
| 2 | R12/R13 | 470 kΩ 0402 | – | OD/OC pull-ups to +BATT — keep the 8205A gates on when the DW01A is unpowered |
| 1 | J2 | USB-C receptacle (charge-only 4/6-pin) | $0.20–0.60 | charge in + 5.1 kΩ CC pull-downs; no D+/D- (flashing via UART0 pads) — placed on power_input |
| 1 | U2 | LIS2DW12 (2x2 mm) | $0.50–1.50 | wake-on-motion interrupt → "if movement" trigger (placed as U2 on accelerometer sheet; LIS2DE12 vs LIS2DW12 still OPEN); BMA400 alt (activity tracking, ~10 µA) |
| 1 | – | LTE antenna (flex PCB, IPEX) | $0.50–2 | |
| 1 | – | GNSS antenna (passive ceramic patch / active) | $1–4 | feeds SIM7670G GNSS input |
| 1 | U3 | 3.3 V LDO ME6211 + decoupling | $0.10–0.30 | MCU rail — placed on power_input |
| 1 | U4 | Modem supply: boost TPS61022 (2.5 A) + L2 1 µH + FB divider + bulk caps | $1–3 | SIM7670G needs 3.4–4.3 V (typ. 4 V) with ~2 A TX peaks; ⚠ currently miswired on the sheet (VIN on 3.3V, VOUT labeled 5V) — to fix |
| – | – | LEDs (status: charge / fix / alert) + resistors | $0.30–1 | |
| – | – | Tact switches (boot / reset), headers, passives | $0.50–1.50 | |
| 1 | – | PCB (JLCPCB, 5 pcs) | $2–5 | |
| – | **Total** | | **~$20–46** | inside the < $50 target |

## Tracking

Keep this file in sync with the schematic (`panic_button_tiny.kicad_sch`) — as of
19-08-2026 (16:37 save): U1 (SIM7670G), U2 (LIS2DW12), U3 (ME6211), U4 (TPS61022), U5 (ESP32-C3),
U6 (DW01A), U7 (8205A), U8 (TP4056), Q1 (Si2305CDS), SW4, BT1, J1, J2, J3, LED1/LED2,
R6–R9 placed (Q2 removed; refs renumbered 16:09 — TP4056 U6→U8, 8205A U8→U7, DW01A U7→U6).
U6/U7 protection pair wired ✓ (re-verified 16:37); the UART section moved to its own
`uart` sheet (J3, TP8–TP13, R10/R11) — needs brains labels; the cell-side net, the
SW4→Q1→+BATT chain, the toggle jumper and R12/R13 remain to wire/add.

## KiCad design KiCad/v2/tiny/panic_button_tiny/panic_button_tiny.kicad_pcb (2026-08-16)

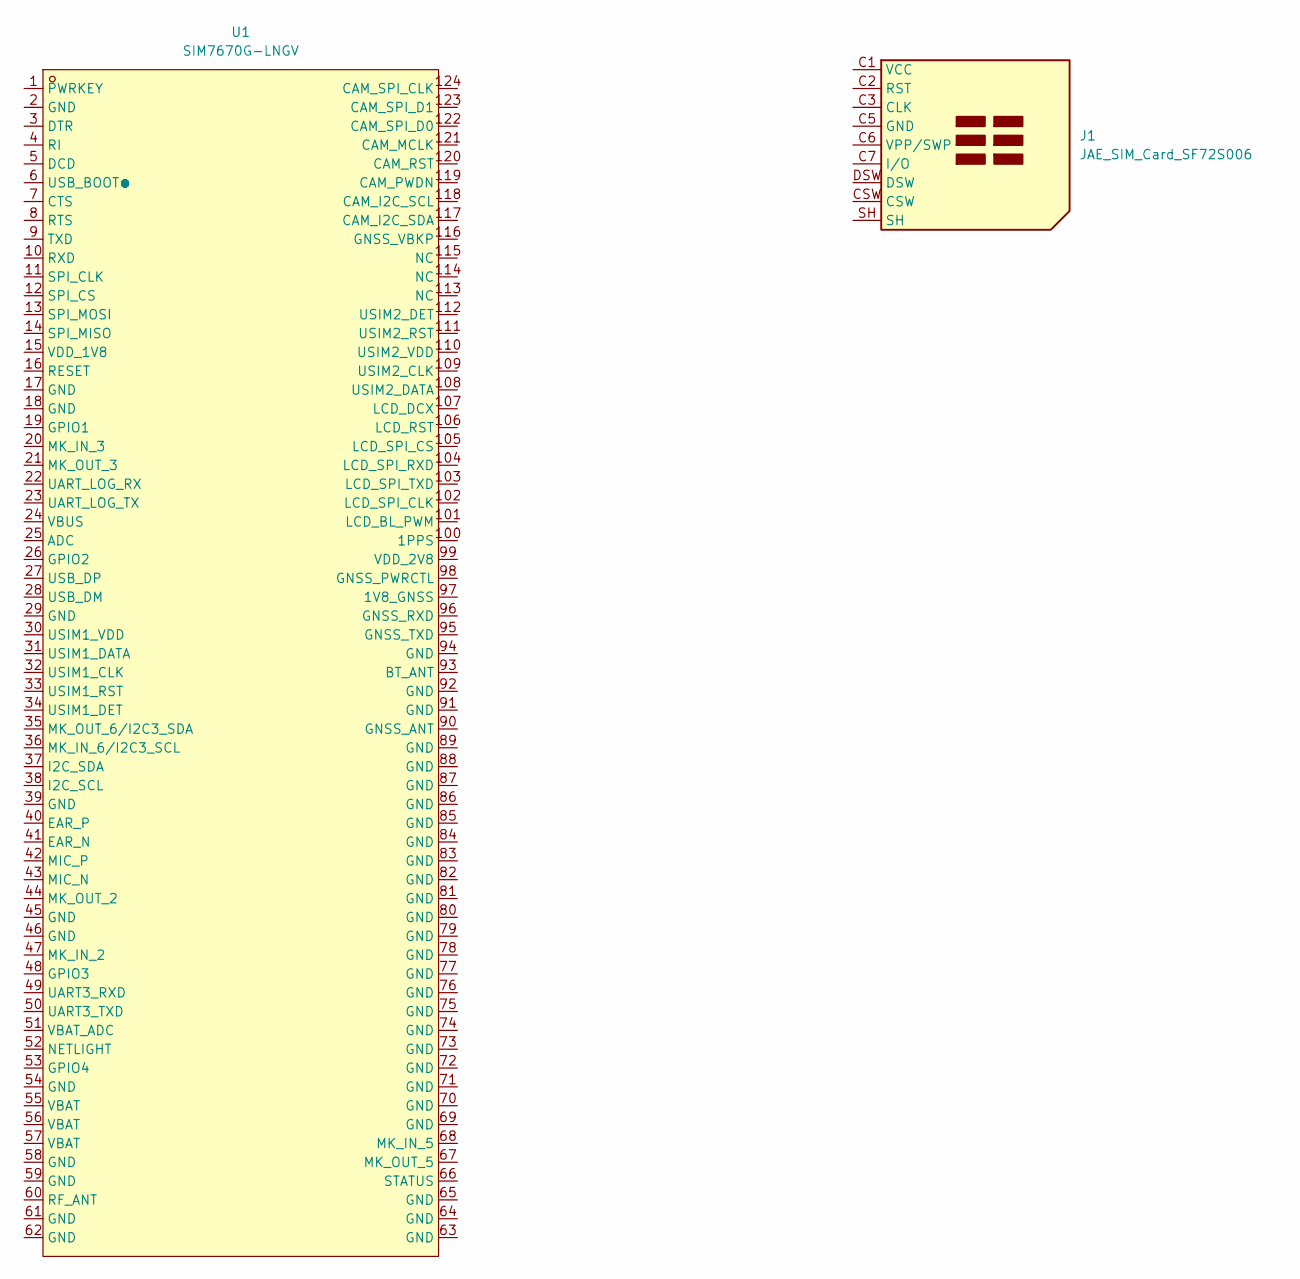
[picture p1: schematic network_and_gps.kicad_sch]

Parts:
J1: JAE_SIM_Card_SF72S006
U1: SIM7670G-LNGV; LCC-124_L24.0-W24.0-P1.0-TL; MPN SIM7670G-LNGV; LCSC Part C45935408

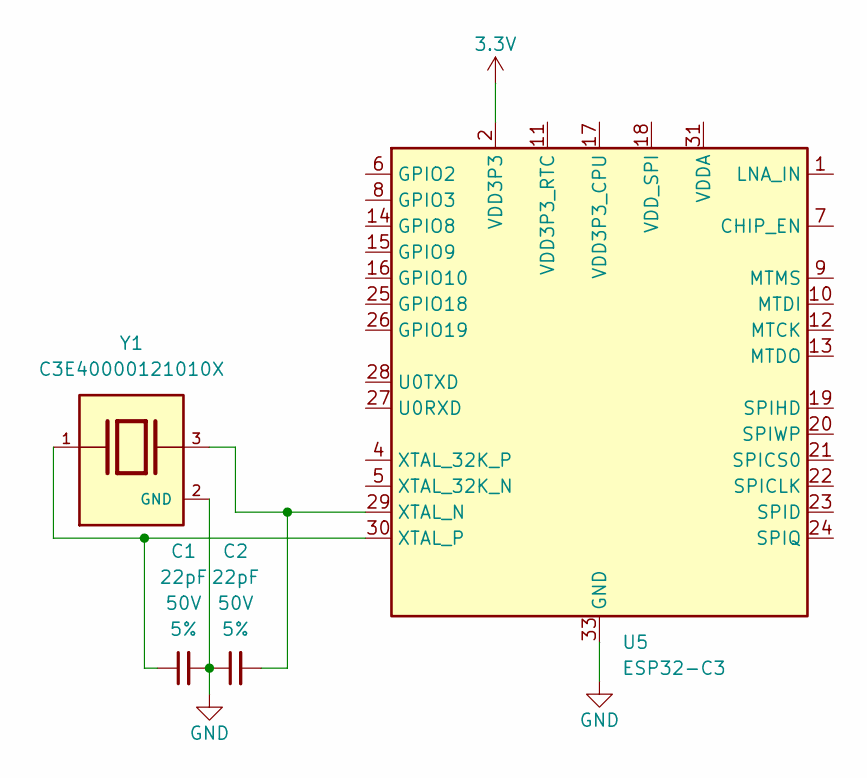
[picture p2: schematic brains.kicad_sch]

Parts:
C1, C2: 22pF; C_0402_1005Metric; Voltage 50V; Tolerance 5%
U5: ESP32-C3; QFN-32-1EP_5x5mm_P0.5mm_EP3.7x3.7mm
Y1: C3E40000121010X; XTAL_C3E40000121010X; PARTREV August 01, 2022

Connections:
3.3V: U5.2 (VDD3P3), U5.3 (VDD3P3); also elsewhere on the board
GND: C1.2, C2.1, U5.33 (GND), Y1.2 (GND), Y1.4 (GND); also elsewhere on the board
unnamed: U5.31 (VDDA), U5.32 (VDDA)
unnamed: C2.2, U5.29 (XTAL_N), Y1.3
unnamed: C1.1, U5.30 (XTAL_P), Y1.1

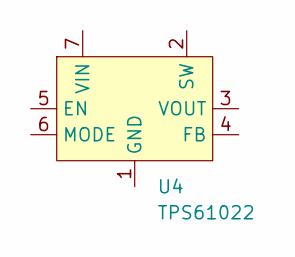
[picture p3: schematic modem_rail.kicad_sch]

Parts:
U4: TPS61022; Texas_RWU0007A_VQFN-7_2x2mm_P0.5mm

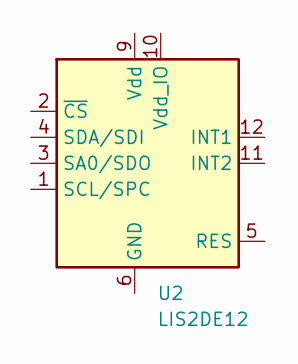
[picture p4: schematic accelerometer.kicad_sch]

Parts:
U2: LIS2DE12; LGA-12_2x2mm_P0.5mm

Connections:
unnamed: U2.6 (GND), U2.7 (GND), U2.8 (GND)

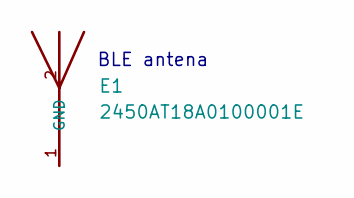
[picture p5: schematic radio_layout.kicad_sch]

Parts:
E1: 2450AT18A0100001E; XCVR_2450AT18A0100001E; PARTREV 4.0

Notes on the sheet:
BLE antena

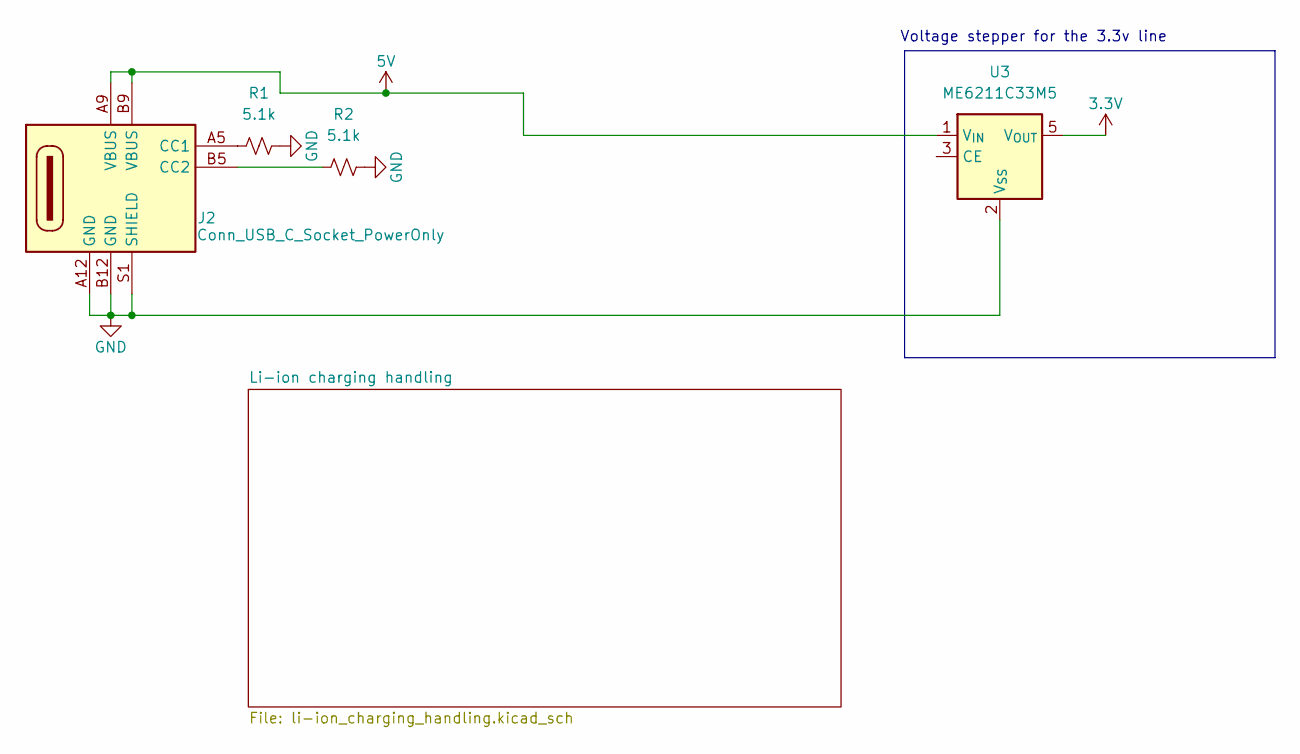
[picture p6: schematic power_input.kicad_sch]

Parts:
J2: Conn_USB_C_Socket_PowerOnly; Conn_USB_C_Socket_GCT_USB4125-GF-A-0190
R1, R2: 5.1k; R_0402_1005Metric
U3: ME6211C33M5; SOT-23-5

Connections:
3.3V: U3.5 (V_{OUT}); also elsewhere on the board
5V: J2.A9 (VBUS), J2.B9 (VBUS), U3.1 (V_{IN})
GND: J2.A12 (GND), J2.B12 (GND), J2.S1 (SHIELD), R1.2, R2.2, U3.2 (V_{SS}); also elsewhere on the board
unnamed: J2.A5 (CC1), R1.1
unnamed: J2.B5 (CC2), R2.1

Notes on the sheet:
Voltage stepper for the 3.3v line

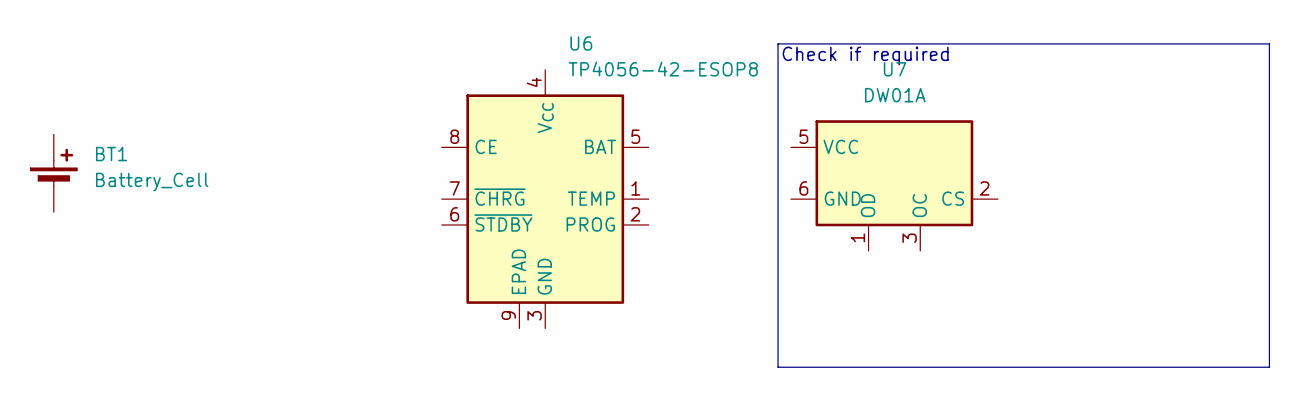
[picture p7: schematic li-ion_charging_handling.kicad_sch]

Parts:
BT1: Battery_Cell; JST_EH_S2B-EH_1x02_P2.50mm_Horizontal
U6: TP4056-42-ESOP8; SOIC-8-1EP_3.9x4.9mm_P1.27mm_EP2.41x3.3mm_ThermalVias
U7: DW01A; SOT-23-6

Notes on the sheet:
Check if required

Board: 2 copper layers, 16 parts (0 on the bottom side), 9 nets, no tracks yet.

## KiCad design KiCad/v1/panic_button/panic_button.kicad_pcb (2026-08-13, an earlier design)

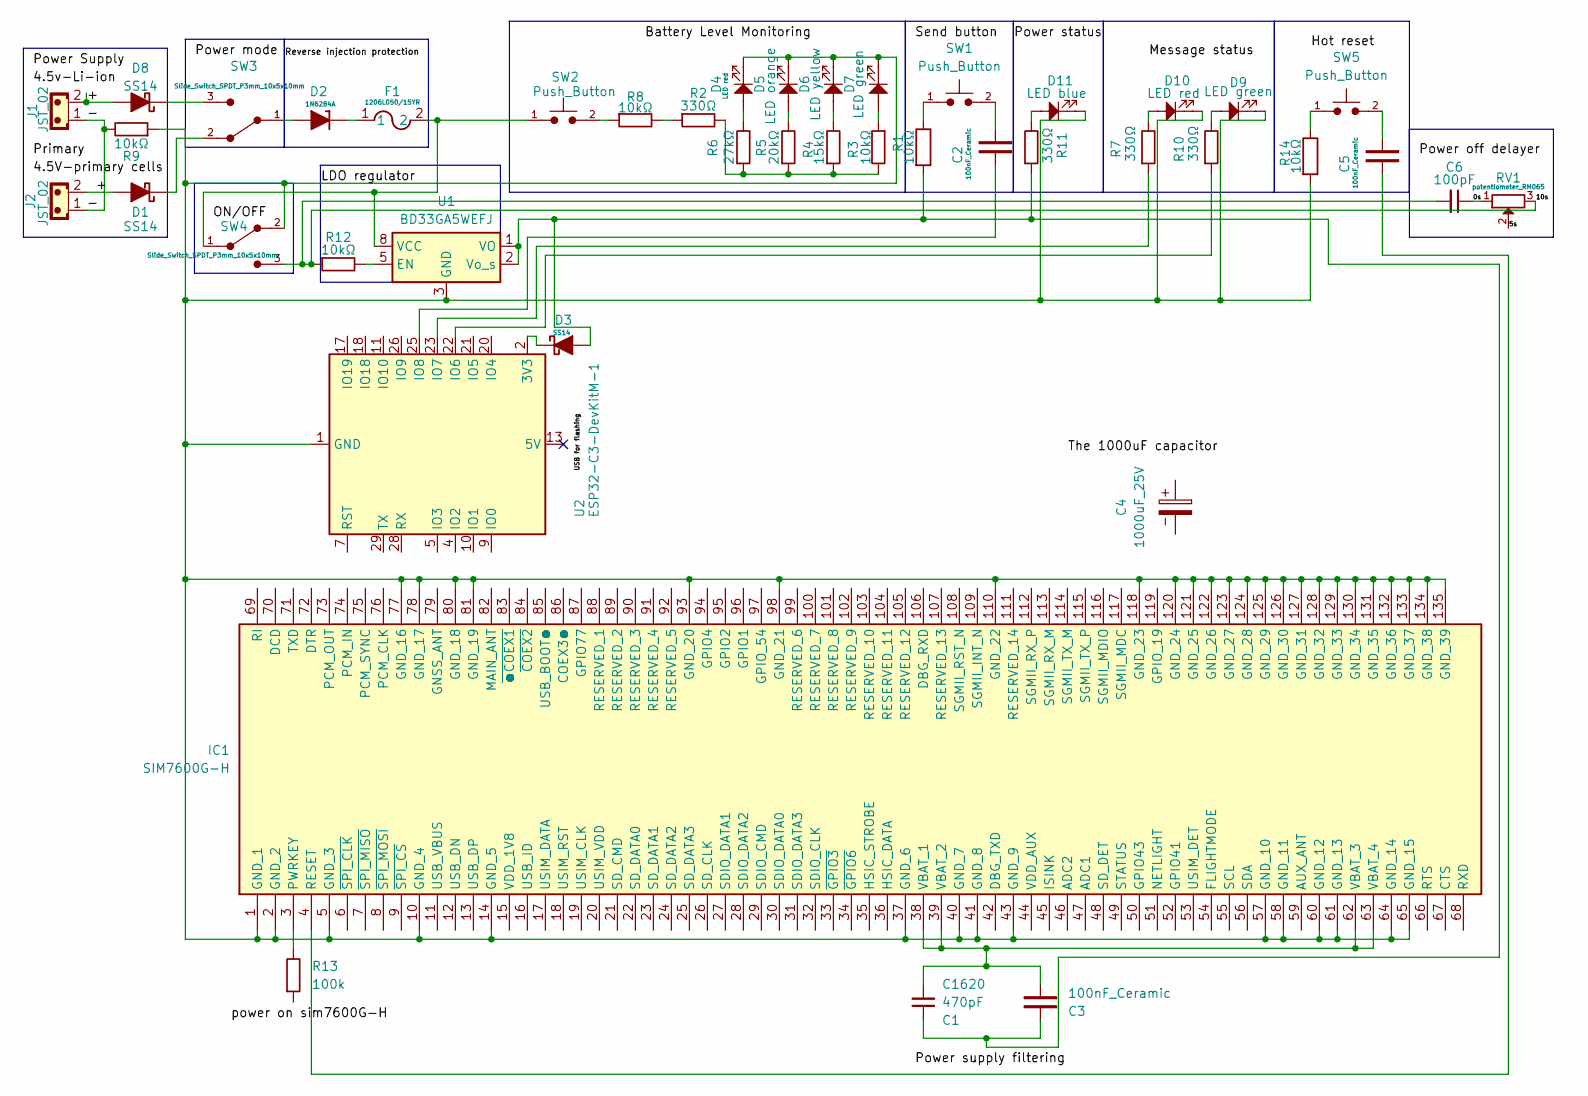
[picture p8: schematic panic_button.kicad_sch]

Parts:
C1: 470pF_0603_25V; C_0603_1608Metric; Part Number C0603C471J5GACTU; JLCPCB ID C1620
C2, C3, C5: 100nF_Ceramic; C_Disc_D5.0mm_W2.5mm_P2.50mm
C4: 1000uF_25V; CP_Radial_D13.0mm_P5.00mm
C6: 100pF_0603_50V; C_0603_1608Metric; Part Number CC0603JRNPO9BN101; JLCPCB ID C14858
D1, D3, D8: SS14; D_SMA
D2: 1N6284A; D_DO-201_P12.70mm_Horizontal_Zener
D4, D10: LED red; LED_D5.0mm
D5: LED orange; LED_D5.0mm
D6: LED yellow; LED_D5.0mm
D7, D9: LED green; LED_D5.0mm
D11: LED blue; LED_D5.0mm
F1: 1206L050/15YR; 1206LSeries_LTF
IC1: SIM7600G-H; SIM7600GH; Manufacturer_Part_Number SIM7600G-H
J1, J2: JST_02; JST_EH_B2B-EH-A_1x02_P2.50mm_Vertical
R1, R14: 10k_0402; R_0402_1005Metric; Part Number RT0402FRE0710KL
R2, R7, R10, R11: 330Ω; R_Axial_DIN0207_L6.3mm_D2.5mm_P10.16mm_Horizontal
R3, R8, R9, R12: 10kΩ; R_Axial_DIN0207_L6.3mm_D2.5mm_P10.16mm_Horizontal
R4: 15kΩ; R_Axial_DIN0207_L6.3mm_D2.5mm_P10.16mm_Horizontal
R5: 20kΩ; R_Axial_DIN0207_L6.3mm_D2.5mm_P10.16mm_Horizontal
R6: 27kΩ; R_Axial_DIN0207_L6.3mm_D2.5mm_P10.16mm_Horizontal
R13: 100k; R_Axial_DIN0207_L6.3mm_D2.5mm_P10.16mm_Horizontal
RV1: potentiometer_RM065; Potentiometer_RM065
SW1, SW2, SW5: Push_Button; SW_PUSH_6mm
SW3, SW4: Slide_Switch_SPDT_P3mm_10x5x10mm
U1: BD33GA5WEFJ; HTSOP-8-1EP_3.9x4.9mm_P1.27mm_EP2.4x3.2mm
U2: ESP32-C3-DevKitM-1

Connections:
/0s: C6.1, RV1.1
/5s: RV1.2
/10s: C6.2, R12.1, RV1.3, SW4.3
/+: D1.2 (A), D8.2 (A), J1.2, J2.2
/-: J1.1, J2.1, R9.2
/LDO regulator: D4.1, D5.1, D6.1, D7.1, D9.1, D10.1, D11.1, IC1.1 (GND_1), IC1.2 (GND_2), IC1.5 (GND_3), IC1.10 (GND_4), IC1.14 (GND_5), IC1.37 (GND_6), IC1.40 (GND_7), IC1.41 (GND_8), IC1.43 (GND_9), IC1.57 (GND_10), IC1.58 (GND_11), IC1.60 (GND_12), IC1.61 (GND_13), IC1.64 (GND_14), IC1.65 (GND_15), IC1.77 (GND_16), IC1.78 (GND_17), IC1.80 (GND_18), IC1.81 (GND_19), IC1.93 (GND_20), IC1.98 (GND_21), IC1.110 (GND_22), IC1.118 (GND_23), IC1.120 (GND_24), IC1.121 (GND_25), IC1.122 (GND_26), IC1.123 (GND_27), IC1.124 (GND_28), IC1.125 (GND_29), IC1.126 (GND_30), IC1.127 (GND_31), IC1.128 (GND_32), IC1.129 (GND_33), IC1.130 (GND_34), IC1.131 (GND_35), IC1.132 (GND_36), IC1.133 (GND_37), IC1.134 (GND_38), IC1.135 (GND_39), R9.1, R14.2, SW4.2, U1.3 (GND), U1.4 (GND), U1.6 (GND), U1.7 (GND), U1.9 (GND), U2.1 (GND), U2.6 (GND), U2.8 (GND), U2.12 (GND), U2.15 (GND), U2.16 (GND), U2.19 (GND), U2.24 (GND), U2.27 (GND), U2.30 (GND)
unnamed: C2.1, SW1.2
unnamed: C5.1, SW5.2
unnamed: D1.1 (K), SW3.2
unnamed: D2.2 (A), SW3.1
unnamed: D2.1 (K), F1.1
unnamed: C1.1, C3.1, D3.2 (A), R1.2, R11.1, U1.1 (VO), U1.2 (Vo_s)
unnamed: D3.1 (K), U2.2 (3V3), U2.3 (3V3)
unnamed: D4.2, R6.2
unnamed: D5.2, R5.2
unnamed: D6.2, R4.2
unnamed: D7.2, R3.1
unnamed: D8.1 (K), SW3.3
unnamed: D9.2, R10.2
unnamed: D10.2, R7.2
unnamed: D11.2, R11.2
unnamed: IC1.3 (PWRKEY), R13.2
unnamed: C5.2, IC1.4 (RESET)
unnamed: C1.2, C3.2, IC1.38 (VBAT_1), IC1.39 (VBAT_2), IC1.62 (VBAT_3), IC1.63 (VBAT_4)
unnamed: R1.1, SW1.1
unnamed: R2.1, R8.2
unnamed: R2.2, R3.2, R4.1, R5.1, R6.1
unnamed: R8.1, SW2.2
unnamed: R14.1, SW5.1
unnamed: R12.2, U1.5 (EN)
unnamed: F1.2, SW2.1, SW4.1, U1.8 (VCC)
unnamed: R10.1, U2.22 (IO6)
unnamed: R7.1, U2.23 (IO7)
unnamed: C2.2, U2.25 (IO8)

Board: 2 copper layers, 43 parts (0 on the bottom side), 33 nets, no tracks yet.

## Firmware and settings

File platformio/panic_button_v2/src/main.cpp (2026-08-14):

#include <Arduino.h>

// put function declarations here:
int myFunction(int, int);

void setup() {
  // put your setup code here, to run once:
  int result = myFunction(2, 3);
}

void loop() {
  // put your main code here, to run repeatedly:
}

// put function definitions here:
int myFunction(int x, int y) {
  return x + y;
}

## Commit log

2026-08-13 [ADD] the current state of the project development
    [panic_button.kicad_pcb, panic_button.kicad_sch, panic_button_dev.kicad_pcb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]
2026-08-14 [UPDATE] the begining of the schematic desing for v2
    [panic_button_dev.kicad_pcb, panic_button_dev.kicad_sch, panic_button_tiny.kicad_pcb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]
2026-08-14 [UPDATE] the schematic ot contain some of the components required for creating the device
    [panic_button_tiny.kicad_sch]
2026-08-15 [ADD] structure to the components used in the project
    [accelerometer.kicad_sch, brains.kicad_sch, modem_rail.kicad_sch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]
2026-08-15 [ADD] the assortment of KiCad symbols I am susceptible to use in the project
2026-08-15 [UPDATE] the structure of the KiCad design for the tiny version
    [accelerometer.kicad_sch, brains.kicad_sch, li-ion_charging_handling.kicad_sch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]
2026-08-15 [UPDATE] the kicad mods submodule
2026-08-16 [UPDATE] the KiCad's .gitignore to not provide the file "C:\Users\User\Desktop\kleplace.log" often created by one of KiCad's modules
2026-08-16 [UPDATE] the KiCad schematic to contain some of the updated designs for the circuit
    [brains.kicad_sch, li-ion_charging_handling.kicad_sch]
2026-08-16 [UPDATE] some of the pcb design and layout
    [brains.kicad_sch, li-ion_charging_handling.kicad_sch, panic_button_tiny.kicad_pcb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]
2026-08-17 [UPDATE] some connections in the circuit
    [radio_layout.kicad_sch]
2026-08-17 [ADD] GND symbols to obvious locations requirering it
    [accelerometer.kicad_sch, network_and_gps.kicad_sch]
2026-08-17 [UPDATE] the AGENTS.md file to hopefully solve the AI bias when reading KiCad schematics
2026-08-17 [UPDATE] the schematic to reflect the connections of the components
    [accelerometer.kicad_sch, brains.kicad_sch, network_and_gps.kicad_sch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]
2026-08-17 [UPDATE] agents.md to contain more information regarding KiCad and user fluidity
2026-08-17 [UPDATE] the AGENTS.md file to contain the explanation of the struggling analysis regarding KiCad connections/pins
2026-08-17 [ADD] a file to help me track the progress of the pcb
2026-08-18 [UPDATE] the schematic with a buzzer and wirering for the different components
    [accelerometer.kicad_sch, brains.kicad_sch, modem_rail.kicad_sch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]
2026-08-18 [UPDATE] the schematic to contain more connections for the battery section
    [brains.kicad_sch, panic_button_tiny.kicad_sch, power_input.kicad_sch]
2026-08-18 [UPDATED] annotations
    [brains.kicad_sch]
2026-08-18 [UPDATE] some connections in the schematic
    [brains.kicad_sch, network_and_gps.kicad_sch, panic_button_tiny.kicad_sch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]
2026-08-18 [UPDATE] connections in the circuit schematic
    [brains.kicad_sch, li-ion_charging_handling.kicad_sch, panic_button_tiny.kicad_sch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]
2026-08-18 [UPDATE] the design logic and the BOM (bill of materials) files
2026-08-18 [UPDATE] connections in the circuits
    [li-ion_charging_handling.kicad_sch, visual.kicad_sch]
2026-08-19 [UPDATE] the battery logic
    [li-ion_charging_handling.kicad_sch, visual.kicad_sch]
2026-08-19 [UPDATE] come logic in the placement of the Li-ion battery charging
    [li-ion_charging_handling.kicad_sch]
2026-08-19 [ADD] a dedicated subsheet for the clocks running the esp32-C3
    [clock.kicad_sch]
2026-08-19 [ADD] a dedicated sheet for the UART programming header
    [uart.kicad_sch]
2026-08-19 [UPDATE] the schematic wirering
    [accelerometer.kicad_sch, brains.kicad_sch, li-ion_charging_handling.kicad_sch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]
2026-08-19 [UPDATE] the schematics annotations
    [accelerometer.kicad_sch, brains.kicad_sch, clock.kicad_sch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]
2026-08-20 [UPDATE] connections in the schematic to better represent the logic flow
    [brains.kicad_sch, clock.kicad_sch, li-ion_charging_handling.kicad_sch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]
2026-08-20 [UPDATE] the schematic with the connections
    [brains.kicad_sch, li-ion_charging_handling.kicad_sch, modem_rail.kicad_sch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]
2026-08-20 [FIX] connection issues in the modem_rail circuit
    [modem_rail.kicad_sch]
2026-08-21 [UPDATE] the schematics to hopefully include better connections
    [brains.kicad_sch, clock.kicad_sch, li-ion_charging_handling.kicad_sch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]
